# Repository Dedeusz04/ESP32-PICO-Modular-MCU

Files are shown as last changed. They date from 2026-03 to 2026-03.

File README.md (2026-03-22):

# ESP32-PICO Modular MCU

A modular hardware design based on the ESP32-PICO microcontroller, split into separate, specialized boards for the processor, power supply, and clock management to ensure high flexibility and easier troubleshooting in embedded development.

## Key Features
- **Modular Architecture**: Core system functionality is divided into distinct, easily interchangeable boards.
- **Processor Module** (`modul_procesora`): Houses the ESP32-PICO core, providing native Wi-Fi/Bluetooth capabilities and GPIO breakouts.
- **Power Supply Module** (`modul_zasilania`): Dedicated hardware for voltage regulation and stable power distribution to all components.
- **Clock Module** (`modul_zegara`): Handles precise clock generation and timing logic.
- **Custom Component Library**: Includes a comprehensive custom Autodesk EAGLE library (`proj_biblioteka.lbr`) with all necessary footprints and symbols used.

For a detailed description of the design, schematic choices, and PCB layouts, refer to the final project report included in this repository: [raport_koncowy_tem1 2 (1).pdf](raport_koncowy_tem1%202%20%281%29.pdf).

## Modules Overview
| Module | Schematic File | Board File | Description |
|---|---|---|---|
| **Processor Module** | `modul_procesora.sch` | `modul_procesora.brd` | Core ESP32-PICO system |
| **Power Supply** | `modul_zasilania.sch` | `modul_zasilania.brd` | Voltage regulation and power management |
| **Clock Module** | `modul_zegara.sch` | `modul_zegara.brd` | Precise timers and RTC |

## Usage
The hardware designs are provided as Autodesk EAGLE files.
1. Clone or download this repository.
2. Open Autodesk EAGLE and ensure `proj_biblioteka.lbr` is added to your active libraries.
3. Open the `.sch` and `.brd` files to view, modify, or manufacture the schematics and PCB designs.

## Contributors
- **Bartosz Kępa**
- **Jan Jamro**
- **Aleksandra Kuś**

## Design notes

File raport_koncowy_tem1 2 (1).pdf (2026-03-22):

| Silesian University of Technology Faculty of Automatic Control, Electronics and Computer Science Department of Graphics, Computer Vision and Digital Systems

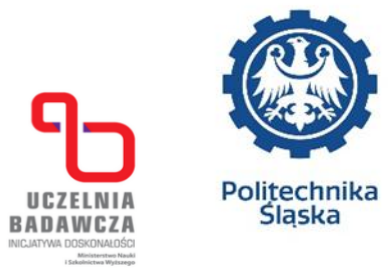
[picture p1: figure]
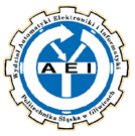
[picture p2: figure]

Rok akademicki | Rodzaj studiów*: | Przedmiot: | Grupa | Sekcja
2024/2025 | SSI | SMiW | 2 | 1
Termin oddania: | 02.07.2025 | Prowadzący: | Mgr inż. Jarosław Paduch
Imię i Nazwisko: Email kierownika: | Bartosz Kępa Jan Jamro Aleksandra Kuś Bk311386@student.polsl.pl

Karta projektu
Temat projektu:
1. Modułowa Jednostka centralna z procesorem ESP32-PICO-D4
- moduł zasilania wejście- 5v (USB) + podłączenie akumulatora z ładowarką
- moduł procesora z wejściami ISP i JTAG przyciski dwa (boot i reset)
- zegar RTC o dokładności około 2-5ppm
Opis projektu:

Projekt oparty jest na modułowej architekturze, co ułatwia rozbudowę i integrację. Jednostka centralna bazuje na ESP32-PICO-D4 z Wi-Fi, Bluetooth, interfejsami ISP i JTAG oraz przyciskami BOOT i RESET. Moduł zasilania wykorzystuje układ BQ24075 z funkcją PowerPath i przetwornicę TPS63020, zapewniając stabilne 3.3V z USB-C lub akumulatora Li-Ion 18650. Zegar RTC DS3231 zapewnia wysoką dokładność (±2 ppm), kompensację temperaturową i zasilanie bateryjne (CR2032). Interfejs użytkownika stanowią mechaniczne przyciski Cherry MX Red. Całość zaprojektowana została z myślą o energooszczędności, kompaktowych wymiarach (płytki 5x6 cm) oraz niezawodności w pracy mobilnej i stacjonarnej.

### 1. Moduł zasilania wejście- 5v (USB) + podłączenie akumulatora z ładowarką

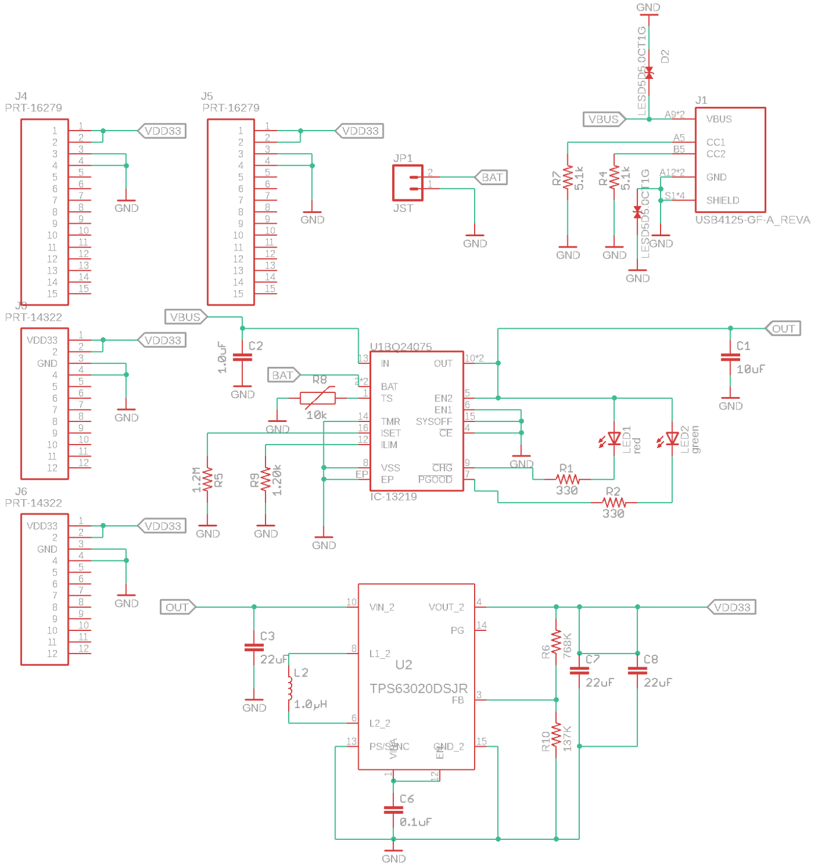
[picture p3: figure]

Rys. 1. Schemat modułu zasilania

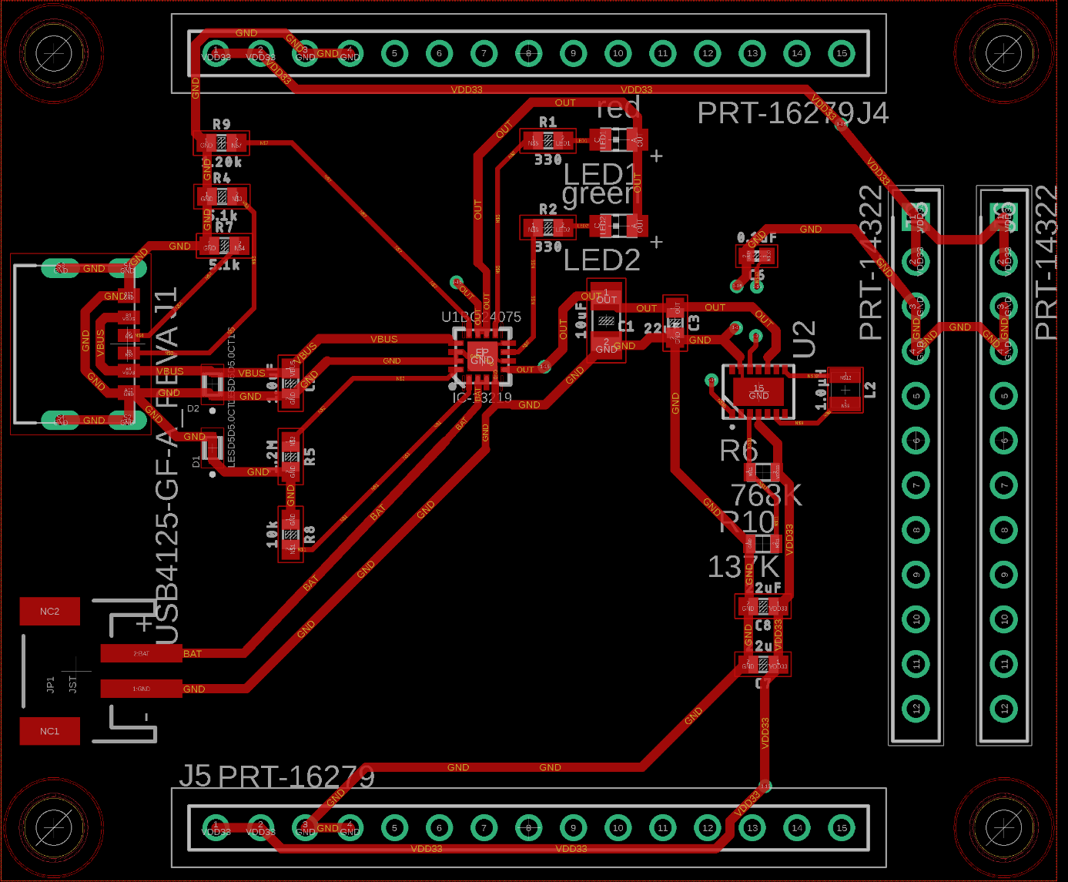
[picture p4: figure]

Rys. 2. Projekt płytki - bez wylanej masy, top warstwa

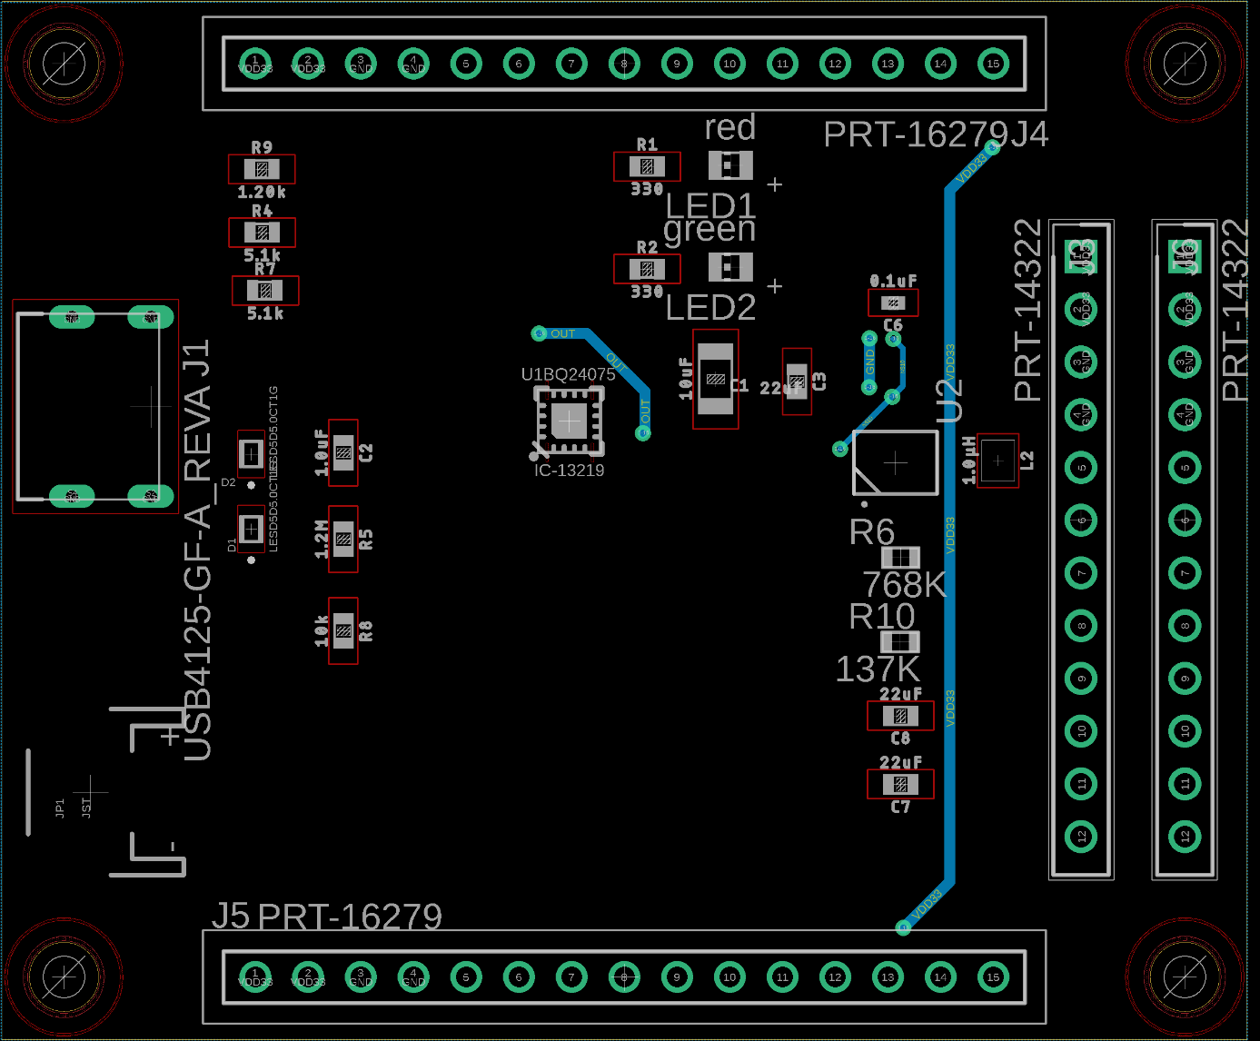
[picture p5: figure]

Rys. 3. Projekt płytki - bez wylanej masy, bottom warstwa

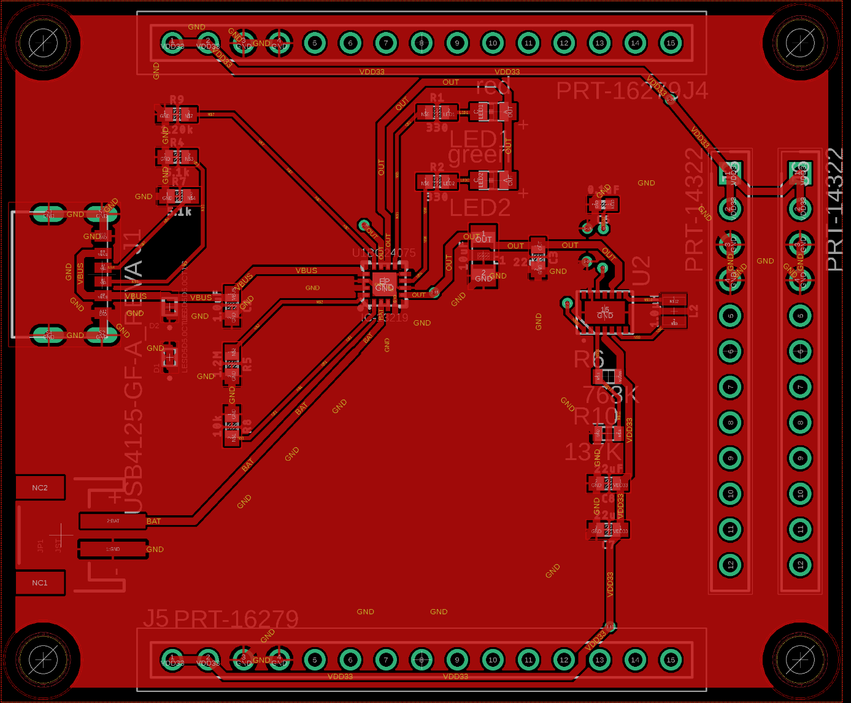
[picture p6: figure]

Rys. 4. Projekt płytki - z wylaną masy, top warstwa

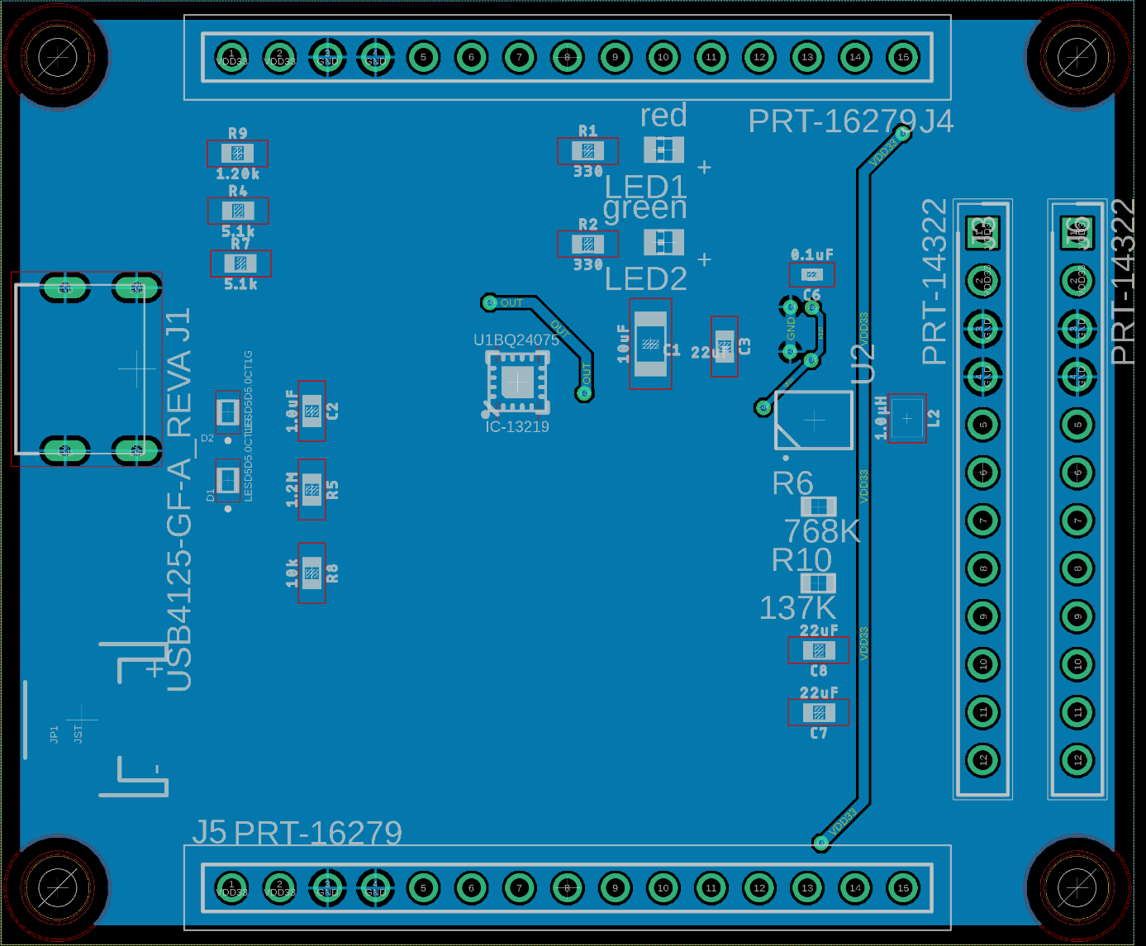
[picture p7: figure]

Rys. 5. Projekt płytki - z wylaną masą, bottom warstwa

Opis schematu modułu zasilania projektu:

Moduł zasilania opiera się na złączu USB-C (USB4125-GF-A) i układzie BQ24075, realizującym inteligentne przełączanie źródła zasilania. Przy podłączonym USB układ zasila system i ładuje akumulator Li-Ion 18650, a po odłączeniu automatycznie przechodzi na zasilanie bateryjne dzięki technologii PowerPath. Akumulator jest podłączony przez złącze JST PH 2.0mm, a termistor NTC (jeśli obecny) monitoruje temperaturę, blokując ładowanie przy zbyt wysokich wartościach. Dioda LED czerwona sygnalizuje ładowanie, a zielona wskazuje zasilanie z USB.

Napięcie z USB (5V) lub baterii (3.7V) jest stabilizowane przez przetwornicę buck-boost TPS63020DSJR, która dostarcza stałe 3.3V do ESP32-PICO-D4. Kondensatory (10µF, 22µF) zapewniają filtrowanie, a cewka (1.5µH) wspiera konwersję napięcia.

Dodatkowo port USB-C posiada Diody ESD-protection chroniące przed zbyt dużym napięciem. Całość masa jak i napięcie zasilania przekazywane są na złącza PRT-14322 oraz PRT-16279 służące do połączenia i zasilania pozostałych płytek.

Tab. 1. Tabela porównawcza przetwornic i stabilizatorów napięcia do 3,3V
Parametr | TPS63020DSJR | LTC3636 | MP2155 | AMS1117-3.3
Producent | Texas Instruments | Analog Devices | Monolithic Power Systems | Advanced Monolithic Systems
Typ | Buck-boost | Buck | Buck-Boost | Stabilizator liniowy
Zakres VIN | 1,8V - 5,5V | 3.1V - 20V | 2V – 5.5V | 4.75V - 15V (dla VOUT=3.3V)
Zakres VOUT | 1,2V - 5,5V | 0.6V - 5V | 1.5V - 5V | Stałe 3.3V
Maks. IOUT | 4A | 6A | 1A | 1A
Sprawność | Do 96% | Do 95% | Do 95% | (VOUT/VIN)*100%, np. 66% przy VIN=5V
Częstotliwość przełączania | 2.4MHz | 500kHz -4MHz | 1MHz | N/A
Cechy specjalne | Jednoindukcyjny, synchroniczna prostownia, tryb oszczędny | Wysoka efektywność, niski pobór prądu w trybie bez obciążenia | Niski prąd spoczynkowy, tryb oszczędny | Prosty, niskokosztowy, ale niska sprawność

Uzasadnienie wyboru TPS63020DSJR TI TPS63020 (https://www.ti.com/product/TPS63020)

- Wysoka sprawność (do 96%): Minimalizuje straty energii, szczególnie przy VIN > VOUT, w porównaniu do AMS1117, który traci energię jako ciepło (np. 0,34W przy VIN=5V, VOUT=3,3V, IOUT=200mA).

- Elastyczność napięcia: Działa zarówno przy VIN < VOUT (bateria <3,3V), jak i VIN > VOUT (USB 5V), w przeciwieństwie do AMS1117, który wymaga VIN > VOUT.
- Duży prąd wyjściowy (4A): Zapewnia zapas dla przyszłych rozszerzeń projektu.
- Zgodność z TI: Ułatwia integrację z innymi komponentami od Texas Instruments.

Dlaczego nie np, stabilizator liniowy (AMS1117)?

Stabilizatory liniowe, takie jak AMS1117, są mniej efektywne, ponieważ nadmiar energii jest rozpraszany jako ciepło. Przy VIN=5V i VOUT=3,3V sprawność wynosi tylko ~66%, co wymaga radiatora. Ponadto, gdy napięcie baterii spadnie poniżej 4,3V, AMS1117 nie może utrzymać 3,3V, co czyni go nieodpowiednim dla aplikacji z baterią.

Tab. 2. Tabela porównawcza modułów podtrzymania akumulatorowego

Parametr | BQ24075 | TP4056 | TP4057 | LTC4054
Producent | Texas Instruments | NanJing Top Power | NanJing Top Power | Analog Devices
Prąd ładowania | Do 1,5A | Do 500mA | Do 500mA | Do 1A
Napięcie wejściowe | 4.35V – 6.4V | 4.0V – 8.0V | 4.0V – 6.5V | 4.25V - 6V
Napięcie baterii | 2.8V – 4.2V | 3.7V - 4,2V | 3,7V - 4,2V | 2.5V – 4.2V
Zarządzanie ścieżką zasilania | Tak | Nie | Nie | Tak
Dodatkowe cechy | Programowalny prąd, limit prądu wejściowego | Ochrona przed przeładowaniem, zwarcia | Podobne do TP4056 | Automatyczne ponowne ładowanie, wykrywanie niskiego napięcia

Uzasadnienie wyboru BQ24075 TI BQ24075 (https://www.ti.com/product/BQ24075)

- Zarządzanie ścieżką zasilania: Umożliwia jednoczesne ładowanie baterii i zasilanie układu, eliminując potrzebę dodatkowych diod lub przełączników, w przeciwieństwie do TP4056/TP4057.
- Wyższy prąd ładowania (1,5A): Umożliwia szybsze ładowanie lub obsługę większych baterii w porównaniu do 1A w TP4056/TP4057.
- Zaawansowane funkcje: Programowalny prąd ładowania i limit prądu wejściowego zwiększają elastyczność.
- Zgodność z TI: Ułatwia integrację z innymi komponentami.

Dlaczego nie np, TP4056/TP4057?

- Brak zarządzania ścieżką zasilania: Wymaga dodatkowych komponentów do przełączania między USB a baterią.
- Niższy prąd ładowania (500A): Mniejsza elastyczność w porównaniu do BQ24075.
- Mniejsza liczba funkcji: Brak zaawansowanych opcji, takich jak programowalny prąd czy limit wejściowy.

Spis elementów układu:

Symbol | Nazwa / Model | Funkcja i opis
J1 | USB4125-GF-A | Złącze USB-C do zasilania i ładowania systemu
JP1 | JST PH 2.0mm | Złącze do podłączenia akumulatora Li-Ion
J3,J6 | PRT-14322 | Złącze 12 pin o standardowym rastrze 2,54 mm do przekazania masy i Vcc pozostałym płytkom
J4,J5 | PRT-16279 | Złącze 15 pin o standardowym rastrze 2,54 mm do przekazania masy i Vcc pozostałym płytkom
U1 | BQ24075 | Układ ładowania Li-Ion z funkcją Power Path
U2 | TPS63020DSJR | Przetwornica buck-boost do stabilizacji 3.3V
C1 | 10µF | Kondensator filtrujący wejście BQ24075
C2 | 10µF | Kondensator filtrujący wyjście BQ24075
C3 | 22µF | Kondensator filtrujący wejście TPS63020DSJR
C7,C8 | 22µF | Kondensator filtrujący wyjście TPS63020DSJR
C6 | 0.1µF | Filtrowanie TPS63020DSJR
L1 | 1.5µH | Cewka dla TPS63020DSJR
R1,R2 | 330Ω | Rezystor ograniczający prąd diody LED
R9 | 1.2kΩ | Programowanie prądu ładowania (ILIM)
R5 | 1.2MΩ | Programowanie prądu ładowania (ISET)
R7,R4 | 5.1kΩ | Rezystory podciągające CC1/CC2 w złączu USB-C
R10,R6 | 137kΩ,768kΩ | Dzielnik napięcia dla FB TPS61022 - do ustawienia wyjścia na 5 V
LED1 | Diode LED Red | Dioda LED czerwona sygnalizacja ładowania
LED2 | Diode LED Green | Dioda LED zielona sygnalizacja zasilania z USB
D2,D1 | ESD5D5.0CT1G | Dioda ESD protection
BAT | Do podłączenia Li-Ion 18650 | Akumulator 3.7V 1000-3000mAh

Wnioski

Moduł zasilania dla ESP32-PICO-D4 został zaprojektowany z myślą o pracy z zasilaniem USB i akumulatorowym. Kluczowym elementem jest BQ24075, zapewniający zarządzanie ścieżką zasilania i bezpieczne ładowanie. Przetwornica TPS63020DSJR gwarantuje stabilne 3.3V z efektywnością (do 96%), a złącze USB4125-GF-A redukuje koszty posiadając jedynie niezbędne piny do bezpiecznego zasilania/ładowania.

### 2. Moduł procesora z wejściami ISP i JTAG przyciski dwa (boot i reset)

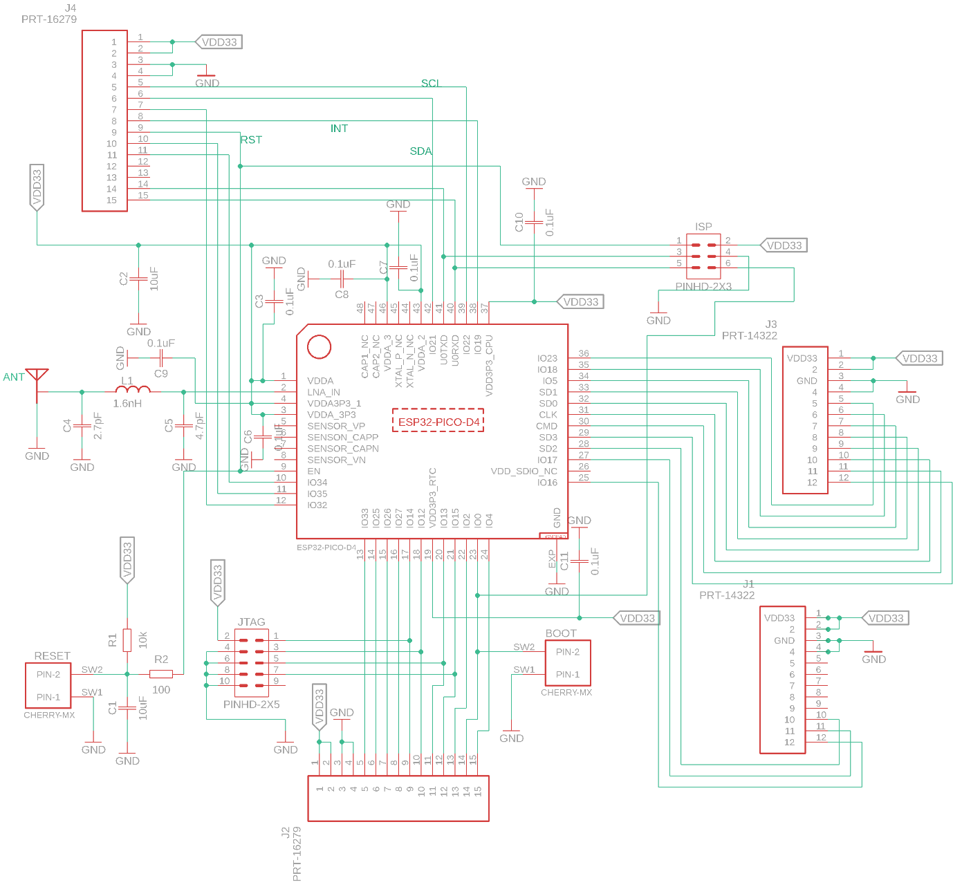
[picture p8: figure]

Rys. 6. Schematu modułu procesora

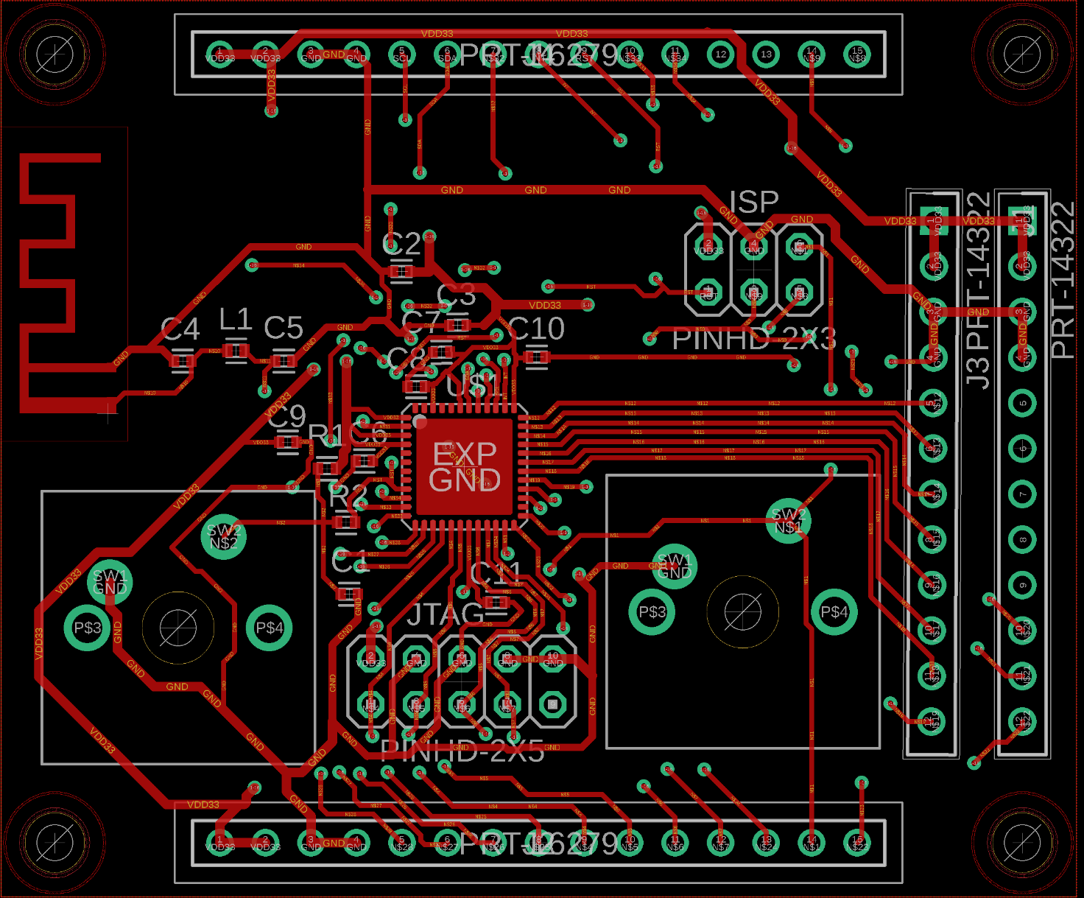
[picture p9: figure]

Rys. 7. Projekt płytki modułu procesora – warstwa TOP bez masy

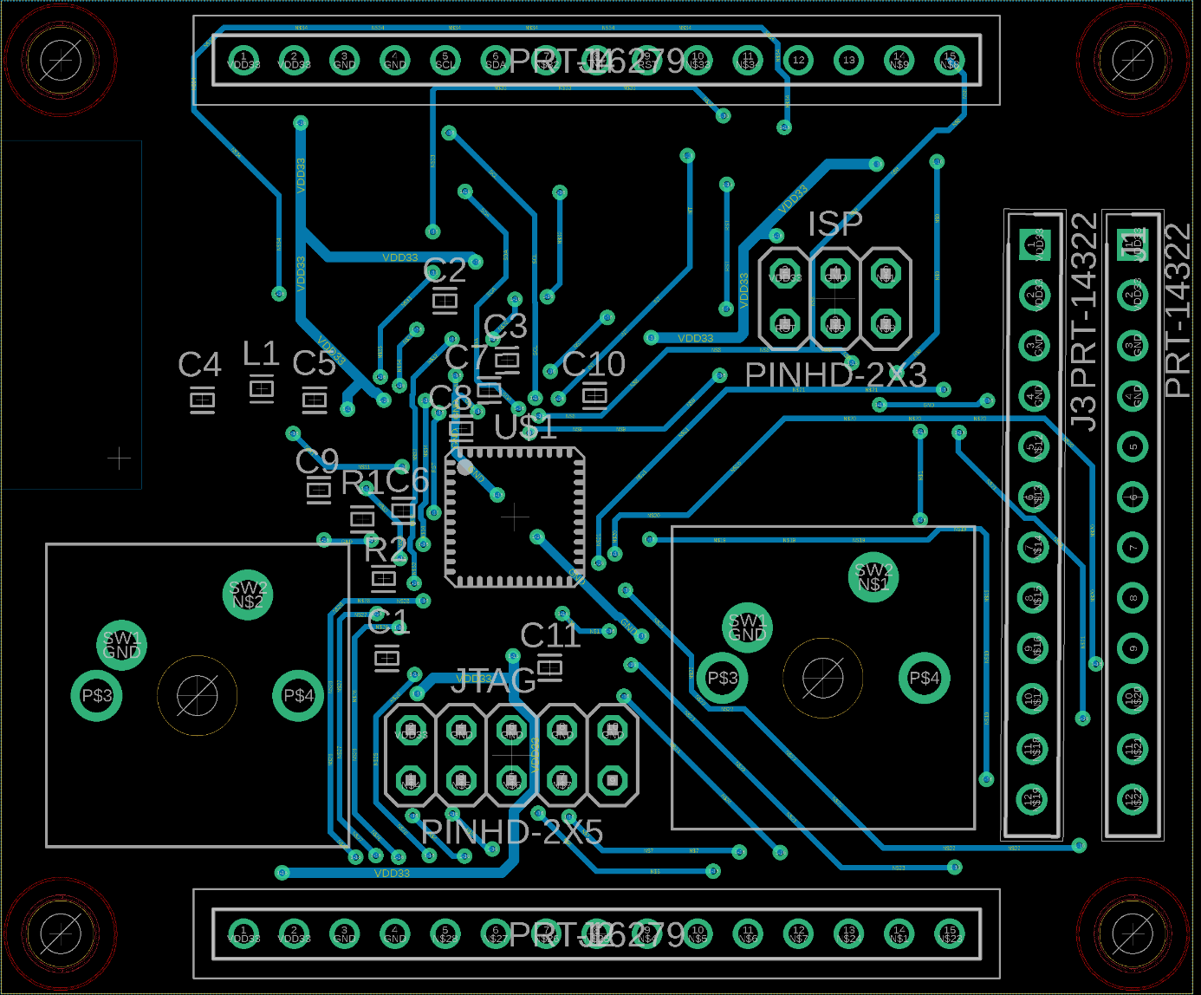
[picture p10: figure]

Rys. 8. Projekt płytki modułu procesora – warstwa BOTTOM bez masy

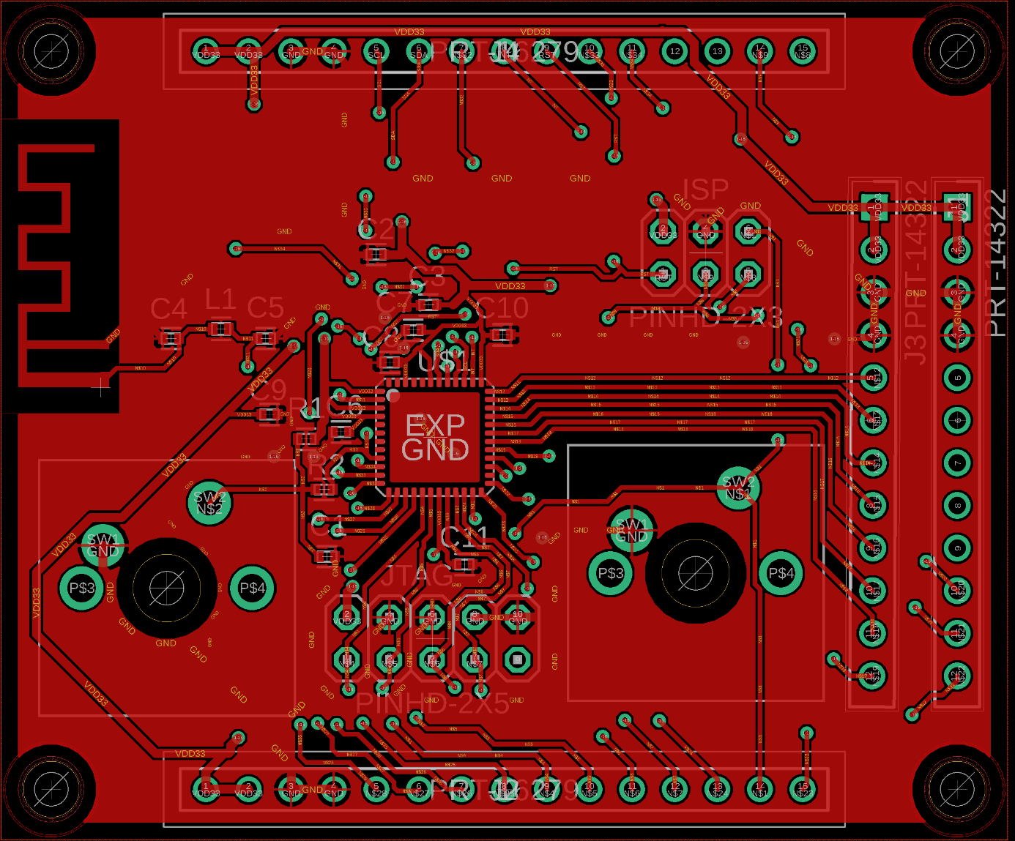
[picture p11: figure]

Rys. 9. Projekt płytki modułu procesora – warstwa TOP z wylaną masą

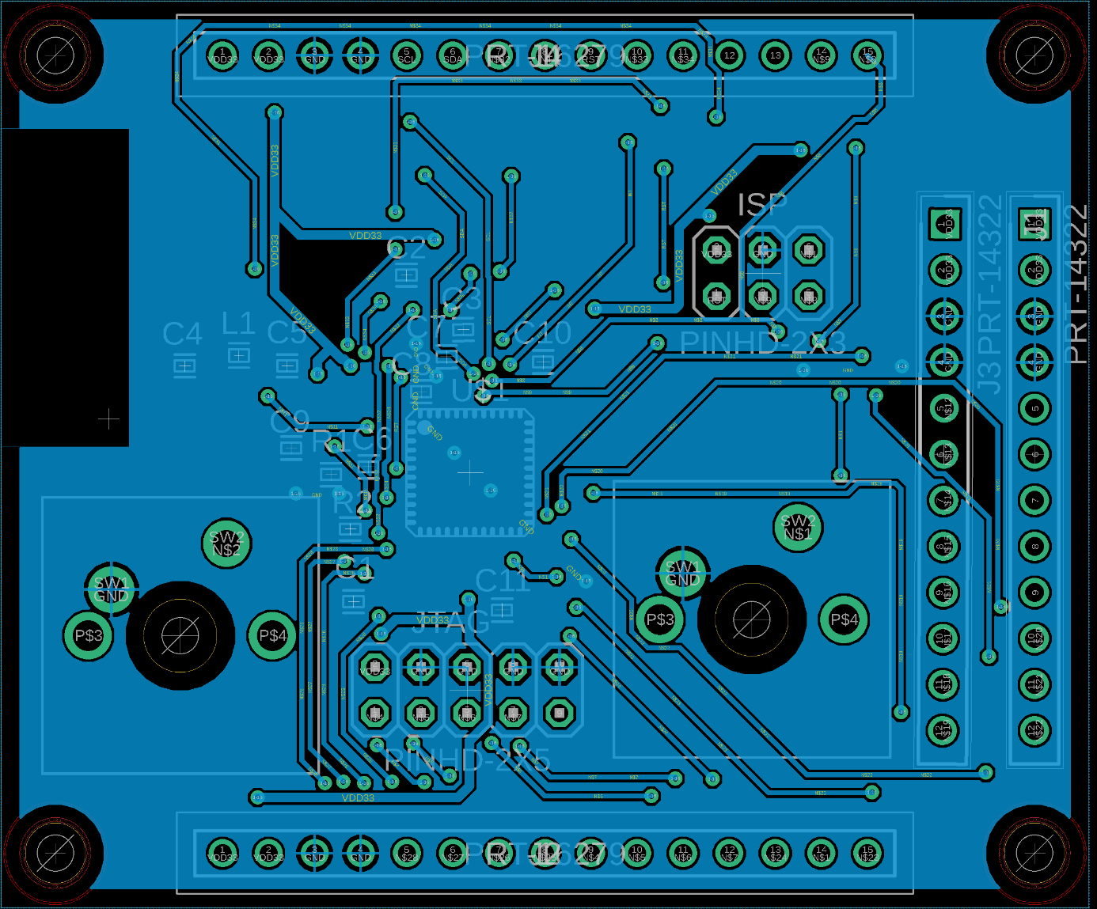
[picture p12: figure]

Rys. 10. Projekt płytki modułu procesora – warstwa BOTTOM z wylaną masą

Opis schematu modułu procesora:
Moduł zrealizowany na procesorze ESP32-PICO-D4. Zawiera złącza do programowania i debugowania: ISP oraz JTAG, do czego należy wykorzystać programator ESP-Prog. Do ISP wykorzystano piny U0RXD oraz U0TXD natomiast dla JTAG piny IO12, IO13, IO14, IO15. Dodatkowo do procesora podłączono dwa przyciski Cherry MX Red– BOOT do przejścia w tryb programowania oraz RESET do restartu procesora, a także antenę WiFi/Bluetooth. Wykorzystano również rezystory, kondensatory oraz cewkę.
Cały moduł zasilany jest oddzielnym modułem zasilania, opisanym w poprzedniej części.
Dodatkowo z procesora na złącza wyprowadzane są sygnały SDA, SCL, INT i RST niezbędne do właściwego działania zegara, opisanego w kolejnej części. Także zostały wyprowadzone na złącza rozszerzeń pozostałe sygnały procesora czyniąc ją w pełni modułową jednostką centralną.
Sam procesor posiada 4 MB pamięci Flash, Wi-Fi 802.11 b/g/n i Bluetooth 4.2 BR/EDR, wewnętrzny oscylator, filtry, i zarządzanie energią. Wymiary 7mm x 7mm, w uśpieniu pobiera bardzo niewielki prąd mnieszy niż 10 uA.

Tab. 3. Porównanie przycisków
Cecha | Cherry MX Red | Gateron Red | Razer Green
Typ | Liniowy | Liniowy | Klikany
Siła nacisku | 45cN | 45cN | 55cN
Długość | 4mm | 4mm | 4mm
Temperatura pracy | Od –40°C do 85°C | Od –40°C do 85°C | Od –40°C do 80°C
Żywotność mechanicza | 50 milionów kliknięć | 60 milionów kliknięć | 80 milionów kliknięć
Rezystancja styku | < 200mΩ | < 200mΩ | < 200mΩ
Dźwięk | Cichy | Cichy | Głośny klik
Cena za sztukę | < 1zł | 1-2 zł | 130 zł

Przyciski Cherry MX Red charakteryzują się płynnością nacisku oraz cichym dzwiękiem, a także estetycznym wyglądem. Ich parametry są bardzo dobre, a dodatkowo cena niewysoka, dlatego są dobrym wyborem do projektu.

Tab.4. Porównanie ESP32-PICO-D4 z ESP8266
Cecha | ESP32-PICO-D4 | ESP8266
Pamięć Flash | 4MB wbudowane | 4MB zewnętrzne
Pamięć RAM | 520 KB SRAM | Około 160KB RAM
WiFi | 802.11 b/g/n | 802.11 b/g/n
Bluetooth | BT 4.2 + BLE | Brak
GPIO | Około 20 (zależnie od konfiguracji) | 11-17 (zależnie od wersji)
JTAG debug | Tak | Nie
Rozmiar | 7mm x 7mm | Około 16mm x 24mm
Pobór w uśpieniu | < 10 mA | Około 20uA
Cena | 10 – 15 zł | 7 – 12 zł

ESP32-PICO-D4 jest nowocześniejszy, szybszy i bardziej funkcjonalny przy niewiele wyższej cenie.
Wnioski

Zaprojektowany moduł umożliwia zarówno programowanie (przez ISP), jak i debugowanie (przez JTAG) mikrokontrolera ESP32-PICO-D4. Zastosowanie przycisków BOOT i RESET pozwala na ręczne wprowadzanie układu w tryb programowania oraz na szybki restart systemu bez konieczności odłączania zasilania. Cały moduł jest niewielki, mieszcząc się na płytce 5cm x 5cm.
Umożliwia on rozbudowanie całego projektu o kolejne moduły, które będą przez niego obsługiwane.

### 3. Zegar RTC o dokładności około 2-5ppm:

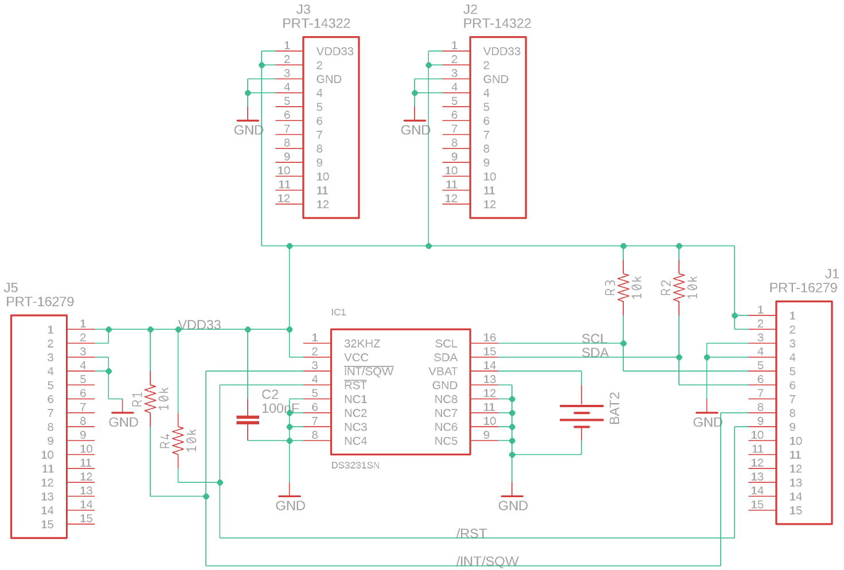
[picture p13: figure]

Rys. 11. Schematu modułu zegara RTC

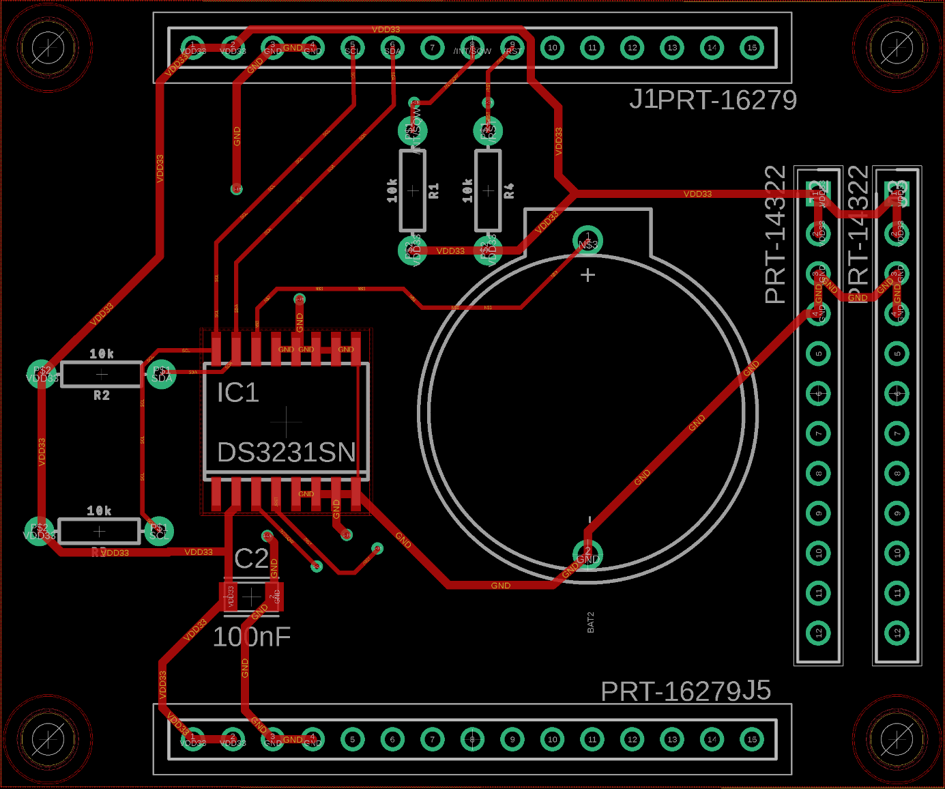
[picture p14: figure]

Rys. 12. Projekt płytki - bez wylanej masy, top warstwa

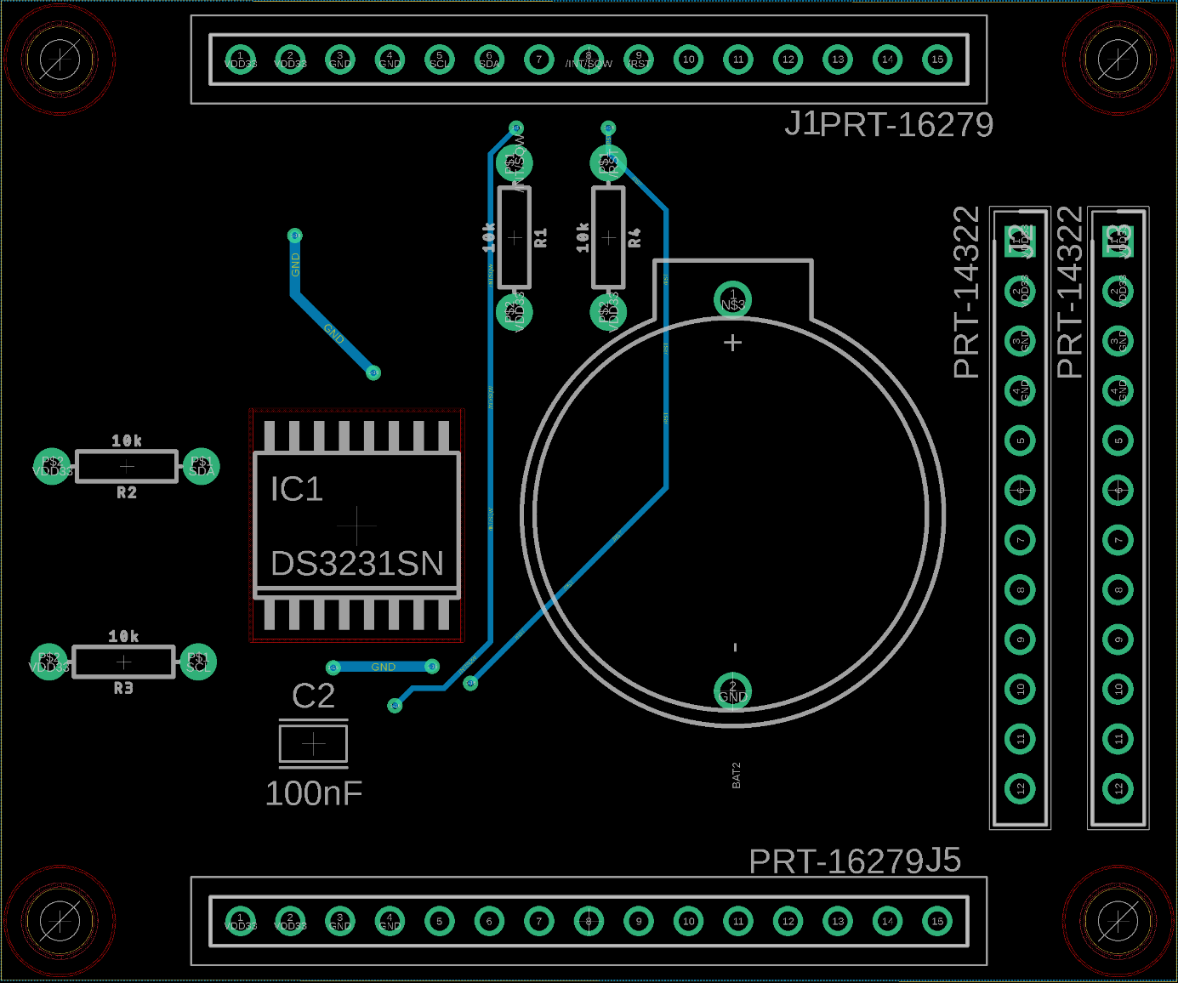
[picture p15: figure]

Rys. 13. Projekt płytki - bez wylanej masy, bottom warstwa

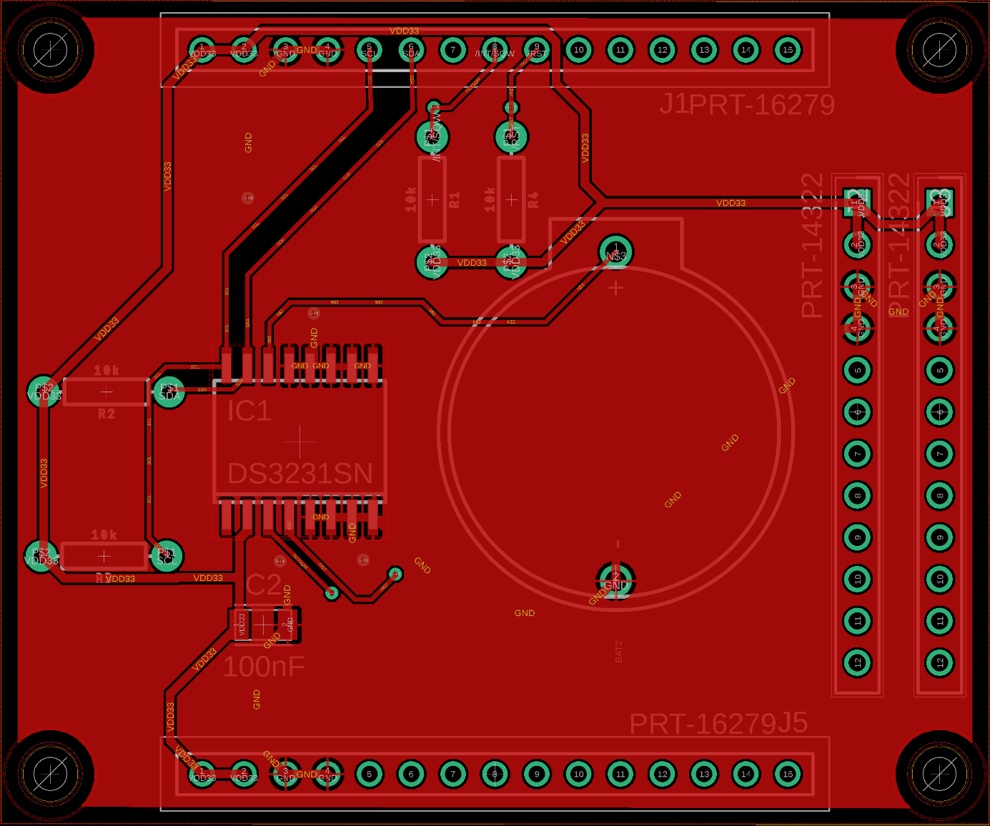
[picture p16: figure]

Rys. 14. Projekt płytki – z wylaną masą, top warstwa

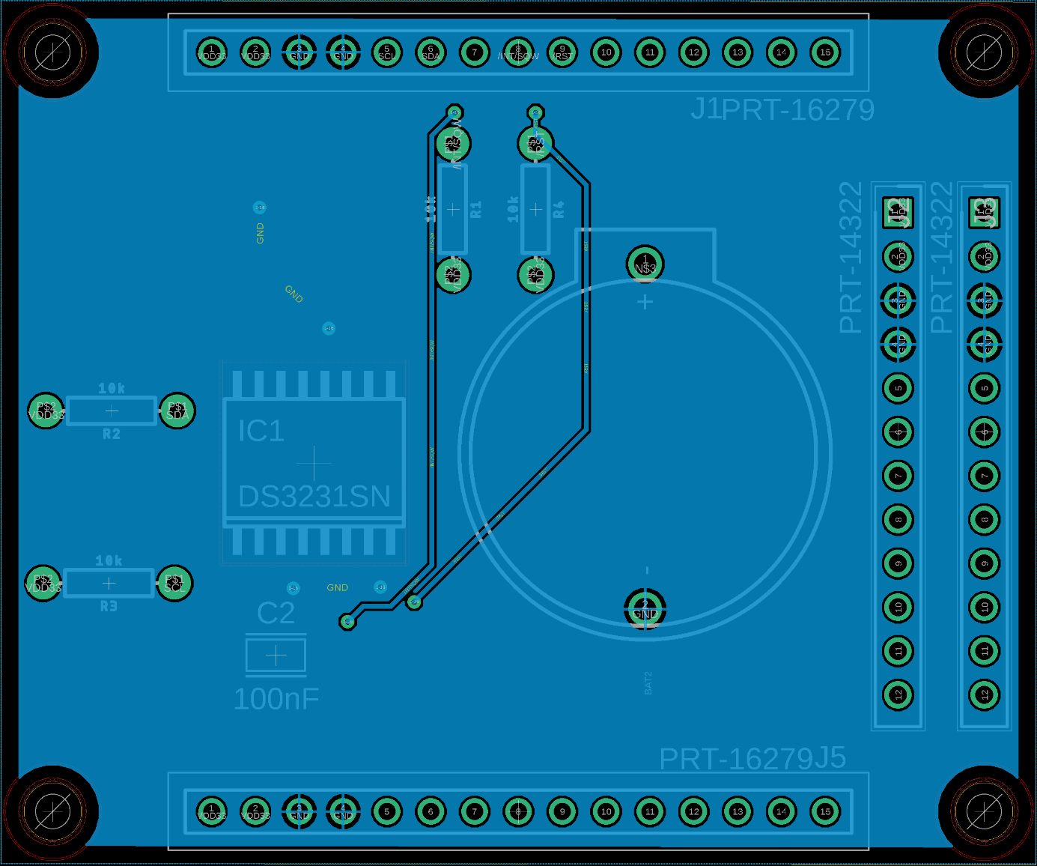
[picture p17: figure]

Rys. 15. Projekt płytki – z wylaną masą, bottom warstwa

Opis schematu modułu zegara RTC:
Na płytce zegara DS3231 zastosowano dwa rezystory podciągające o wartości 10 kΩ w obudowie SMD 0805, które łączą linie SDA i SCL z napięciem 3,3 V. Rezystory te gwarantują, że magistrala I²C zawsze wraca do stanu wysokiego, nawet gdy żaden układ nie przeciąga jej w dół, co zapobiega szumom i nieprawidłowym odczytom. Bezpośrednio przy pinie VCC DS3231 znajduje się ceramiczny kondensator 100 nF (X7R, 0805), którego niska wartość ESR i dobra stabilność temperaturowa umożliwia:
- tłumienie wysokoczęstotliwościowych zakłóceń na linii zasilania,
- szybkie dostarczanie prądu przy nagłych pikach poboru (np. podczas odbierania lub nadawania danych).
Aby zachować ciągłość pomiaru czasu przy zaniku głównego zasilania, moduł wyposażono w gniazdo na baterię typu CR2032, montowane powierzchniowo. Dodatni biegun ogniwa podłączono do pinu VBAT, a ujemny do masy. W praktyce oznacza to, że:
- gdy VDD33 spadnie poniżej progu, DS3231 automatycznie przełącza się na zasilanie bateryjne,
- wskazania zegara pozostają poprawne przez wiele lat – nawet w przypadku długotrwałego braku zasilania.
Na płytce zastosowano dwa złącza PRT-14322 oraz dwa złącza PRT-16279 o standardowym rastrze 2,54 mm. Złącze J5,J3,J2, służące wyłącznie do dostarczania zasilania, ma tylko dwa aktywne piny:
- pin 1,2 to VDD33,
- pin 3,4 — GND.
Natomiast złącze J1 wyprowadza wszystkie sygnały niezbędne do współpracy DS3231 z zewnętrznym układem: dostępne są tu piny VDD33, GND, linie SCL i SDA magistrali I²C, wyjście przerwania lub sygnału kwadratowego INT/SQW oraz opcjonalny pin RESET. Rozmieszczenie pinów w dwóch rzędach ułatwia prowadzenie ścieżek i montaż przewodów w zestawach prototypowych czy obudowach modułowych. Dzięki temu zestawowi złączy moduł jest wszechstronnie gotowy do integracji z różnymi mikrokontrolerami lub systemami pomiarowymi.

Tab. 5. Tabela porównawcza zegarów RTC
Model | DS3231 | DS1307 | PCF85263A | MCP79410
Dokładność | ±2 ppm | ~ 20–50 ppm | ~10-50 ppm | ±5 ppm
Interfejs | I²C do 400 kHz | I²C do 100 kHz | I²C do 400 kHz | I²C do 400 kHz
Komunikacja | I²C | I²C | I²C/SPI | I²C
Wbudowany oscylator | Tak | Nie | Tak | Nie
Kompensacja temperatury | Tak | Nie | Częściowa | Nie
Napięcie wejściowe | 2,3–5,5V | 5V (moduł), 2,0– 3,5V | 1,8–3,6V | 1,8 – 5,5 V
Napięcie wyjściowe | – | – | – | –
Maksymalny prąd | ~200 µA | 800 nA | ~200 nA | ~230 µA
Bateria | Brak (CR2032) | Brak (CR2032) | Brak (CR1220) | Brak (CR2032)
Napięcie baterii VBAT | 2,3 V…5,5 V | 2,0 V…3,5 V | — (pomija VBAT; bat. w zewn. układzie) | 1,8 – 5,5 V
Backup bateryjny | Ręczne przełączanie, UL-recognized | Automatyczne przełączenie przy VCC<VTP | Detekcja niskiego VDD, alarm VL | Automatyczne przełączanie
Zakres temp. pracy | 0 °C…+70 °C (S) –40 °C…+85 °C (SN) | 0 °C…+70 °C (Z) –40 °C…+85 °C (ZN) | –40 °C…+85 °C | –40 … +85 °C
Pinout | 16-pin SOIC (300 mil) | 8-pin DIP-8 / SO-8 | 8-pin SO-8 / TSSOP-8 | 8-pin SO-8 / MSOP-8
Funkcje dodatkowe | TCXO, czujnik temp., kalibracja starzenia | 56 B SRAM, wyjście SQW/OUT | alarmy, timer, CLKOUT z 4 trybami | kalendarz, 1 kB EEPROM, 2 alarmy, PWM, cyfrowy trim
Obudowa | SO-16 | DIP-8 / SO-8 | SO-8 / TSSOP-8 | SO-8 / MSOP-8
Koszt | ~30 zł | ~23 zł | ~30 zł | ~10 zł
Wymaga kwarcu zewn.? | Nie | Tak (32.768 kHz) | Nie | Tak (32,768 kHz)
Uwagi | Bardzo dokładny | Tani, popularny, | Nowoczesny, trudniej dostępny | Dodatkowa pamięć, brak kompensacji

W projekcie zdecydowano się na zastosowanie układu RTC DS3231. Wybór ten został podjęty na podstawie analizy parametrów kilku popularnych układów czasu rzeczywistego. Celem było znalezienie rozwiązania, które zapewni wysoką dokładność oraz łatwość integracji z mikrokontrolerem ESP32-PICO-D4.
- Zapewnia wysoką dokładność rzędu ±2 ppm, co spełnia wymagania projektowe dotyczące precyzji odmierzania czasu.
- Posiada wbudowany oscylator kwarcowy oraz kompensację temperaturową, co gwarantuje stabilne działanie niezależnie od warunków otoczenia.
- Nie wymaga zewnętrznego rezonatora, dzięki czemu upraszcza projektowanie układu PCB i redukuje liczbę komponentów.
- Umożliwia zasilanie bateryjne (np. CR2032), co pozwala na podtrzymanie czasu w przypadku przerwy w zasilaniu głównym.
- Komunikuje się przez magistralę I²C, co ułatwia integrację z mikrokontrolerem ESP32-PICO-D4 i zmniejsza zapotrzebowanie na linie sygnałowe.
Ze względu na powyższe cechy, DS3231 został uznany za najbardziej odpowiedni układ RTC do realizacji założeń projektu.

Wnioski:
Wykorzystanie układu DS3231 z wbudowanym rezonatorem TCXO i kompensacją temperaturową zapewnia wyjątkową dokładność pomiaru czasu (rzędu ±2 ppm) w szerokim zakresie temperatur, a dzięki automatycznemu przełączaniu na zasilanie bateryjne (ogniwo CR2032) moduł zachowuje ciągłość wskazań nawet przy zaniku głównego VDD. Krótkie ścieżki do rezystorów podciągających 10 kΩ na liniach SDA ,SCL, /RST, /INT/SQW oraz kondensator 100 nF przy pinie VCC tłumią zakłócenia i stabilizują napięcie, co przekłada się na bezbłędną komunikację I²C. Złącza PRT-14322 (J5 i J1) oraz PRT-16279 (J2 i J3) o wyraźnym pinoucie i zwartej, kątowej formie znacznie ułatwiają montaż i integrację z mikrokontrolerami czy obudowami modułowymi. Ponadto pozostawione pola lutownicze na dodatkowe filtry czy diody ochronne pozwalają w prosty sposób dostosować projekt do specyficznych wymagań środowiskowych lub norm EMC.

Oceny wystawione przez kierownika projektu:

Praca nad projektem przebiegała bardzo dobrze, z pełnym zaangażowaniem i przestrzeganiem terminów. Członkowie zespołu wykazali się inicjatywą i wsparciem dla siebie nawzajem, co przełożyło się na efektywną pracę. Przy ocenie brano pod uwagę zarówno wartość merytoryczną wkładu, jak i zaangażowanie w pracę zespołową.
Jan Jamro: 5
Aleksandra Kuś: 5

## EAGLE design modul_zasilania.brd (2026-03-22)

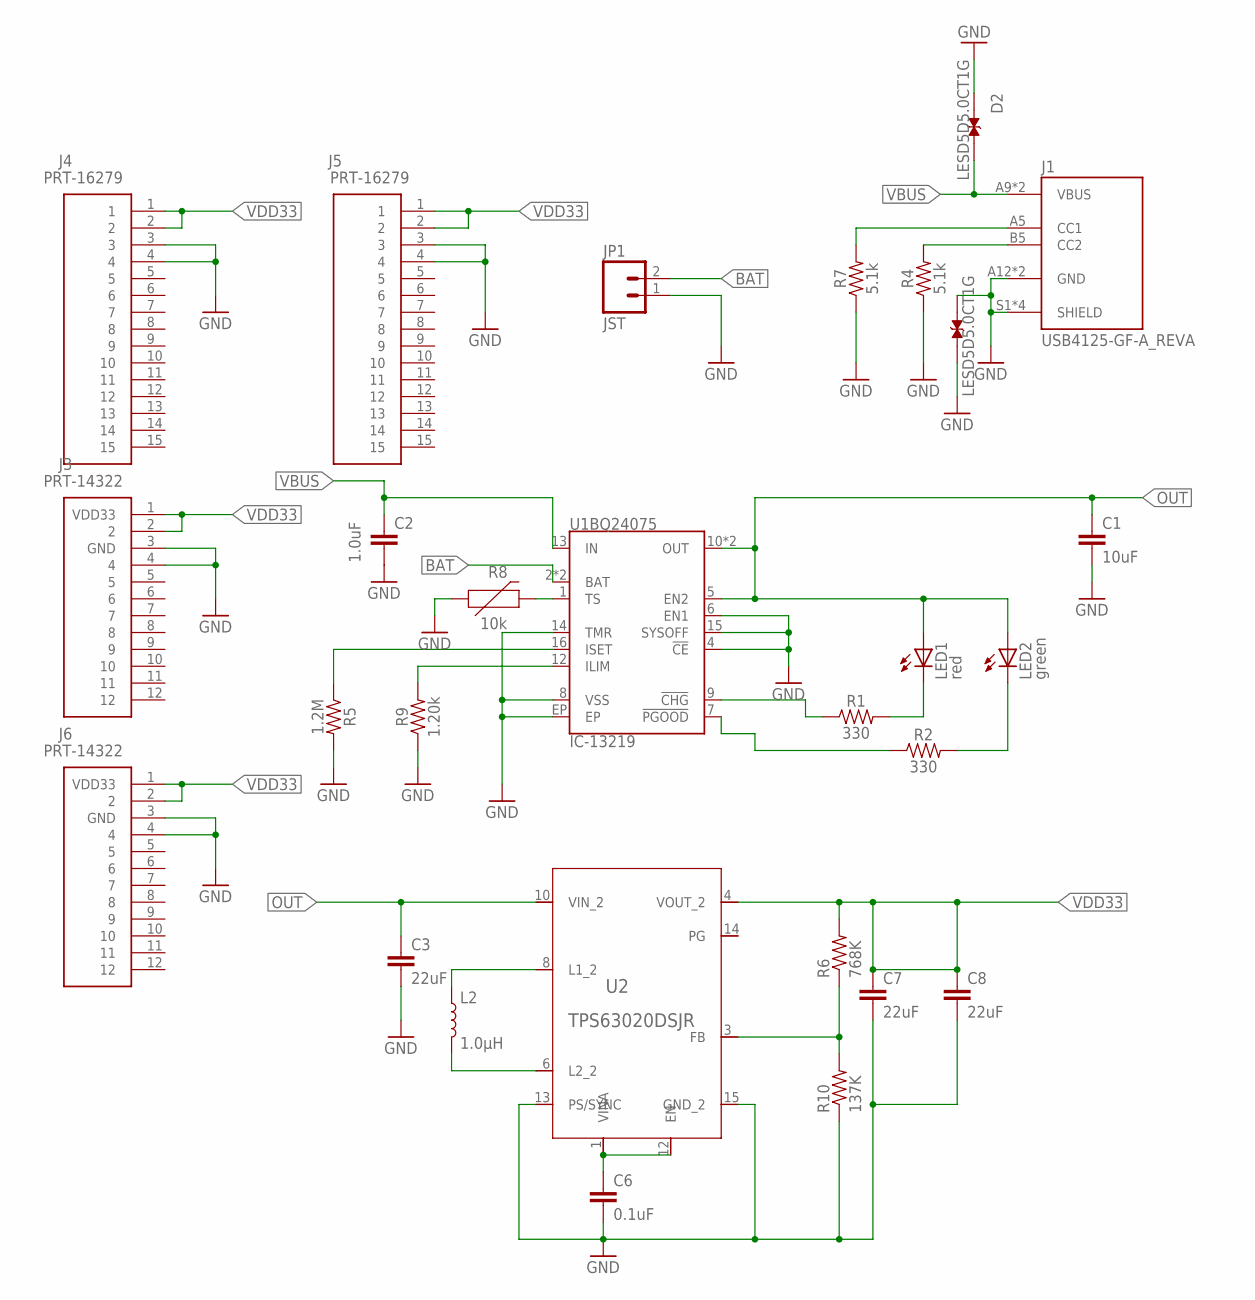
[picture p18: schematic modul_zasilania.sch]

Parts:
C1: 10uF; 1206
C2: 1.0uF; 0603
C3, C7, C8: 22uF; 0603
C6: 0.1uF; 0402
D1, D2: LESD5D5.0CT1G; TVS_LESD5D5.0CT1G
J1: USB4125-GF-A_REVA; GCT_USB4125-GF-A_REVA
J3, J6: PRT-14322; RHDR12W87P0X254_1X12_3103X250X
J4, J5: PRT-16279; PRT16279
JP1: JST; JST-2-SMD
L2: 1.0μH; 0805-WIDE
LED1: red; CHIP-LED0805
LED2: green; CHIP-LED0805
R1, R2: 330; 0603
R4, R7: 5.1k; 0603
R5: 1.2M; 0603
R6: 768K; 0603
R8: 10k; 0603@1
R9: 1.20k; 0603
R10: 137K; 0603
U1BQ24075: IC-13219; PVQFN-N16
U2: TPS63020DSJR; R-PVSON-N14

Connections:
BAT: JP1.2, U1BQ24075.2 (BAT), U1BQ24075.3 (BAT)
GND: C1.2, C2.2, C3.2, C6.2, C7.2, C8.2, D1.1, D1.2, D2.1, J1.A12 (GND), J1.B12 (GND), J1.S1 (SHIELD), J1.S2 (SHIELD), J1.S3 (SHIELD), J1.S4 (SHIELD), J3.3 (GND), J3.4, J4.3, J4.4, J5.3, J5.4, J6.3 (GND), J6.4, JP1.1, R4.1, R5.2, R7.1, R8.1, R9.1, R10.1, U1BQ24075.4 (!CE!), U1BQ24075.6 (EN1), U1BQ24075.8 (VSS), U1BQ24075.14 (TMR), U1BQ24075.15 (SYSOFF), U1BQ24075.EP, U2.13 (PS/SYNC), U2.15 (GND_2)
LED1: LED1.C, R1.2
LED2: LED2.C, R2.2
unnamed: R8.2, U1BQ24075.1 (TS)
unnamed: R5.1, U1BQ24075.16 (ISET)
unnamed: J1.B5 (CC2), R4.2
unnamed: J1.A5 (CC1), R7.2
unnamed: R1.1, U1BQ24075.9 (!CHG!)
unnamed: R2.1, U1BQ24075.7 (!PGOOD!)
unnamed: R9.2, U1BQ24075.12 (ILIM)
unnamed: L2.2, U2.6 (L2_2)
unnamed: C6.1, U2.1 (VINA), U2.12 (EN)
unnamed: R6.1, R10.2, U2.3 (FB)
unnamed: L2.1, U2.8 (L1_2)
OUT: C1.1, C3.1, LED1.A, LED2.A, U1BQ24075.5 (EN2), U1BQ24075.10 (OUT), U1BQ24075.11 (OUT), U2.10 (VIN_2)
VBUS: C2.1, D2.2, J1.A9 (VBUS), J1.B9 (VBUS), U1BQ24075.13 (IN)
VDD33: C7.1, C8.1, J3.1 (VDD33), J3.2, J4.1, J4.2, J5.1, J5.2, J6.1 (VDD33), J6.2, R6.2, U2.4 (VOUT_2)

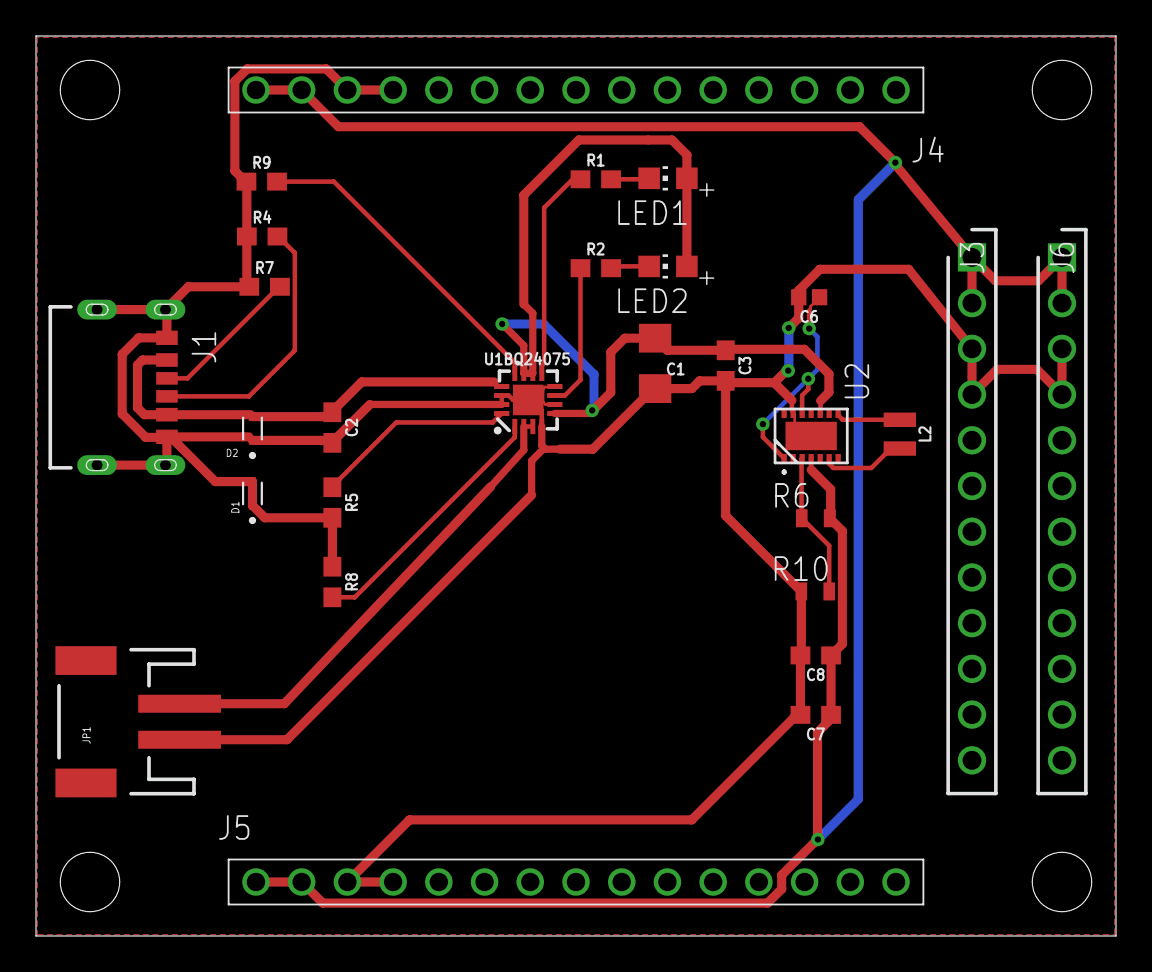
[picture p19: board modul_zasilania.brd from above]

Board: 2 copper layers, 60.0 x 50.0 mm, 32 parts (0 on the bottom side), 18 nets.

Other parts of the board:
STANDOFF1, STANDOFF2, STANDOFF3, STANDOFF4: STAND-OFF

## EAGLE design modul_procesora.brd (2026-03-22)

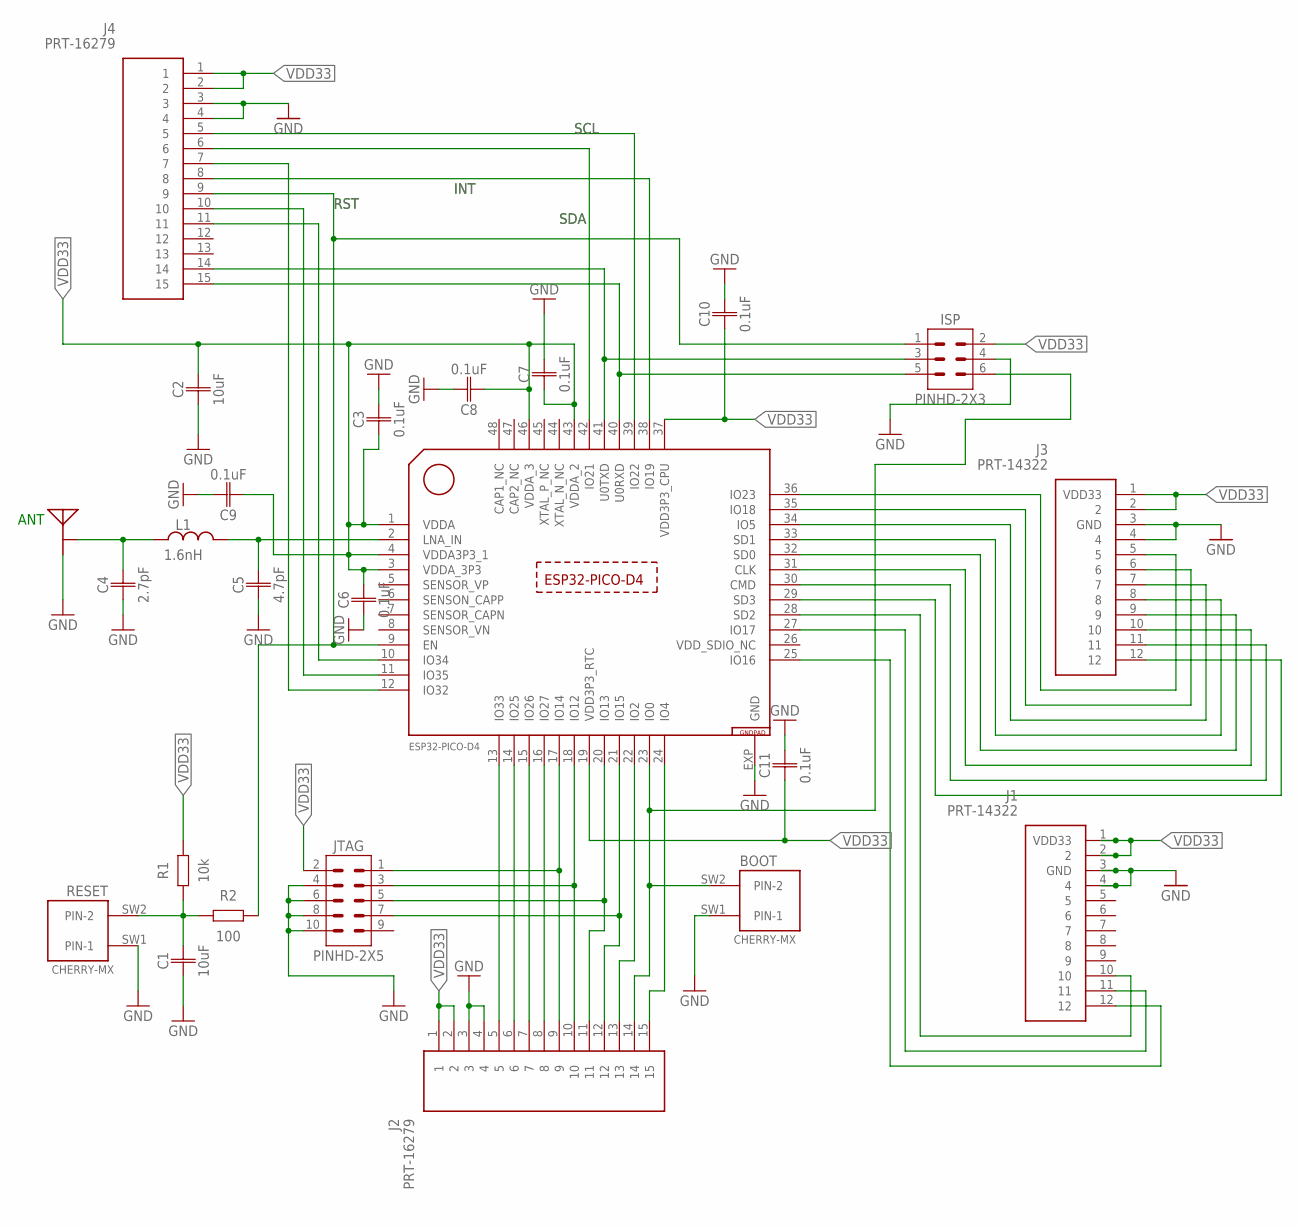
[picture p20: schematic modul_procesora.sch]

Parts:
ANT: ANT; MEANDER-ANT
BOOT: BOOT; CHERRY-MX
C1, C2: 10uF; CAPC1005X60
C3, C6, C7, C8, C9, C10, C11: 0.1uF; CAPC1005X60
C4: 2.7pF; CAPC1005X60
C5: 4.7pF; CAPC1005X60
ISP: PINHD-2X3; 2X03
J1, J3: PRT-14322; RHDR12W87P0X254_1X12_3103X250X
J2, J4: PRT-16279; PRT16279
JTAG: PINHD-2X5; 2X05
L1: 1.6nH; INDC1006X60N
R1: 10k; RESC1005X40
R2: 100; RESC1005X40
RESET: CHERRY-MX
U$1: ESP32-PICO-D4; QFN48

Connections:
GND: ANT.FEED, BOOT.SW1 (PIN-1), C1.1, C2.1, C3.2, C4.1, C5.1, C6.1, C7.2, C8.2, C9.2, C10.2, C11.2, ISP.4, J1.3 (GND), J1.4, J2.3, J2.4, J3.3 (GND), J3.4, J4.3, J4.4, JTAG.4, JTAG.6, JTAG.8, JTAG.10, RESET.SW1 (PIN-1), U$1.EXP (GND)
INT: J4.8, U$1.38 (IO19)
unnamed: BOOT.SW2 (PIN-2), ISP.6, J2.14, U$1.23 (IO0)
unnamed: C1.2, R1.1, R2.1, RESET.SW2 (PIN-2)
unnamed: J2.9, JTAG.1, U$1.17 (IO14)
unnamed: J2.10, JTAG.3, U$1.18 (IO12)
unnamed: J2.11, JTAG.5, U$1.20 (IO13)
unnamed: J2.12, JTAG.7, U$1.21 (IO15)
unnamed: ISP.5, J4.15, U$1.40 (U0RXD)
unnamed: ISP.3, J4.14, U$1.41 (U0TXD)
unnamed: ANT.GND, C4.2, L1.1
unnamed: C5.2, L1.2, U$1.2 (LNA_IN)
unnamed: J3.5, U$1.36 (IO23)
unnamed: J3.6, U$1.35 (IO18)
unnamed: J3.7, U$1.34 (IO5)
unnamed: J3.8, U$1.33 (SD1)
unnamed: J3.9, U$1.32 (SD0)
unnamed: J3.10, U$1.31 (CLK)
unnamed: J3.11, U$1.30 (CMD)
unnamed: J3.12, U$1.29 (SD3)
unnamed: J1.10, U$1.28 (SD2)
unnamed: J1.11, U$1.27 (IO17)
unnamed: J1.12, U$1.25 (IO16)
unnamed: J2.15, U$1.24 (IO4)
unnamed: J2.13, U$1.22 (IO2)
unnamed: J2.8, U$1.16 (IO27)
unnamed: J2.7, U$1.15 (IO26)
unnamed: J2.6, U$1.14 (IO25)
unnamed: J2.5, U$1.13 (IO33)
unnamed: J4.7, U$1.12 (IO32)
unnamed: J4.10, U$1.11 (IO35)
unnamed: J4.11, U$1.10 (IO34)
RST: ISP.1, J4.9, R2.2, U$1.9 (EN)
SCL: J4.5, U$1.39 (IO22)
SDA: J4.6, U$1.42 (IO21)
VDD33: C2.2, C3.1, C6.2, C7.1, C8.1, C9.1, C10.1, C11.1, ISP.2, J1.1 (VDD33), J1.2, J2.1, J2.2, J3.1 (VDD33), J3.2, J4.1, J4.2, JTAG.2, R1.2, U$1.1 (VDDA), U$1.3 (VDDA_3P3), U$1.4 (VDDA3P3_1), U$1.19 (VDD3P3_RTC), U$1.37 (VDD3P3_CPU), U$1.43 (VDDA_2), U$1.46 (VDDA_3)
VDD_SDIO_NC: U$1.26 (VDD_SDIO_NC)

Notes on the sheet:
ANT
SDA
INT
RST
SCL

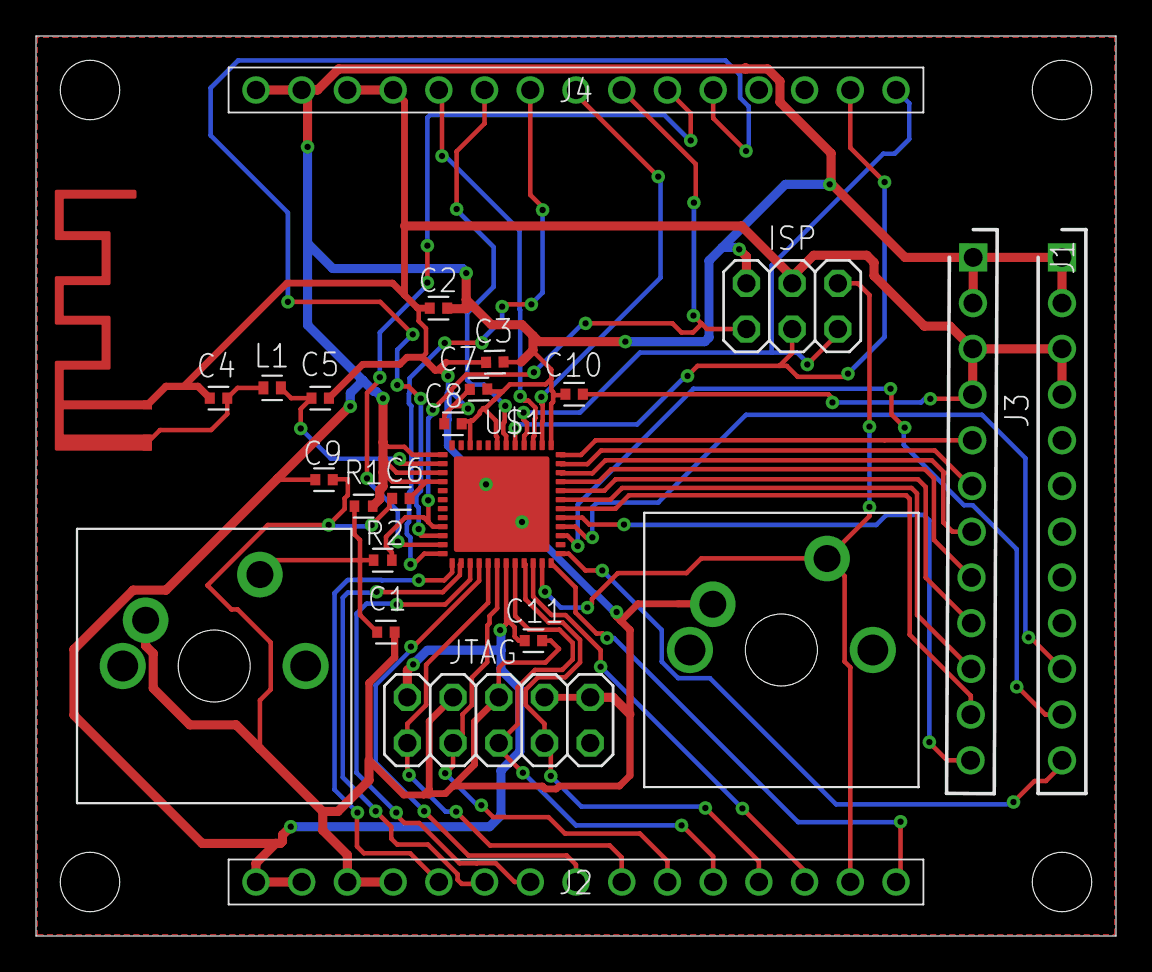
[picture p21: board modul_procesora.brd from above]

Board: 2 copper layers, 60.0 x 50.0 mm, 28 parts (0 on the bottom side), 36 nets.

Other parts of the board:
STANDOFF1, STANDOFF2, STANDOFF3, STANDOFF4: STAND-OFF

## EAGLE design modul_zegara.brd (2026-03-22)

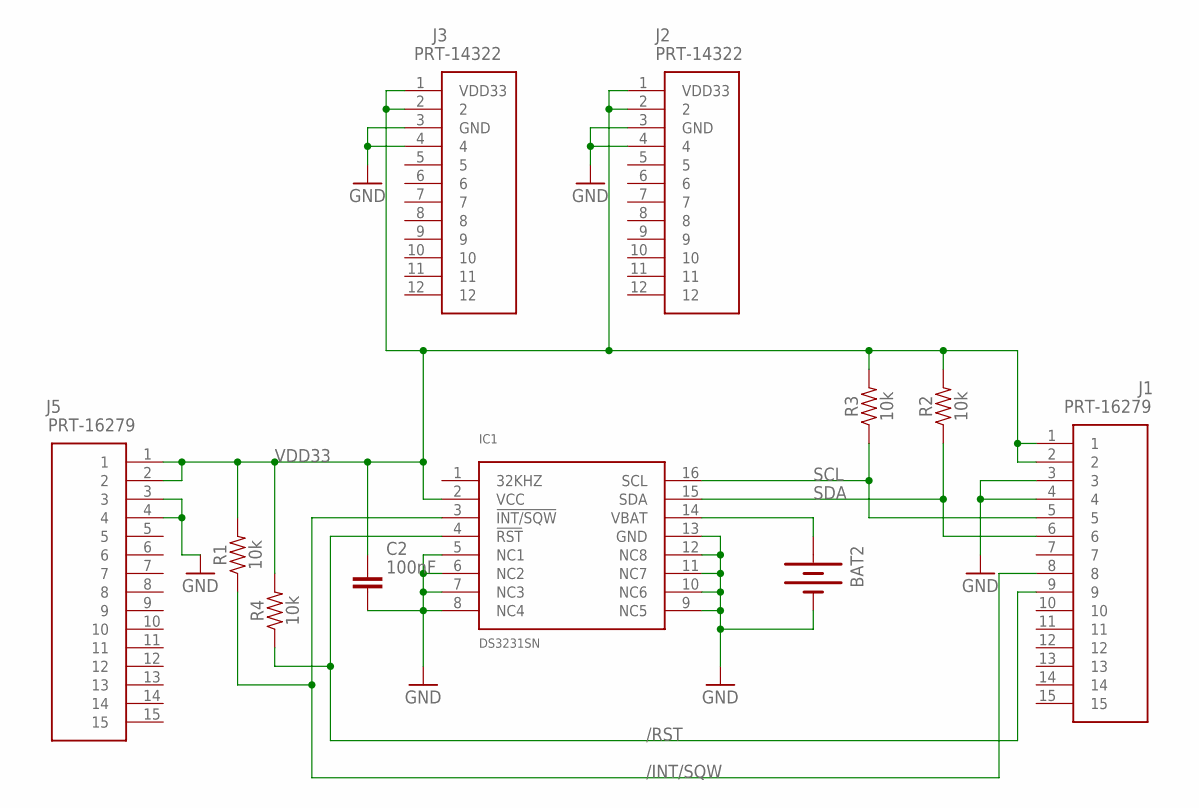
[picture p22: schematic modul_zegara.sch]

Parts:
BAT2: BATTERY20PTH; BATTCOM_20MM_PTH
C2: 100nF; CAPC3216X135
IC1: DS3231SN; SO16W
J1, J5: PRT-16279; PRT16279
J2, J3: PRT-14322; RHDR12W87P0X254_1X12_3103X250X
R1, R2, R3, R4: 10k; AXIAL-0.3

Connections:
/INT/SQW: IC1.3 (!INT/SQW), J1.8, R1.P$1 (1)
/RST: IC1.4 (!RST), J1.9, R4.P$1 (1)
GND: BAT2.2 (-), C2.2, IC1.5 (NC1), IC1.6 (NC2), IC1.7 (NC3), IC1.8 (NC4), IC1.9 (NC5), IC1.10 (NC6), IC1.11 (NC7), IC1.12 (NC8), IC1.13 (GND), J1.3, J1.4, J2.3 (GND), J2.4, J3.3 (GND), J3.4, J5.3, J5.4
unnamed: BAT2.1 (+), IC1.14 (VBAT)
SCL: IC1.16 (SCL), J1.5, R3.P$1 (1)
SDA: IC1.15 (SDA), J1.6, R2.P$1 (1)
VDD33: C2.1, IC1.2 (VCC), J1.1, J1.2, J2.1 (VDD33), J2.2, J3.1 (VDD33), J3.2, J5.1, J5.2, R1.P$2 (2), R2.P$2 (2), R3.P$2 (2), R4.P$2 (2)

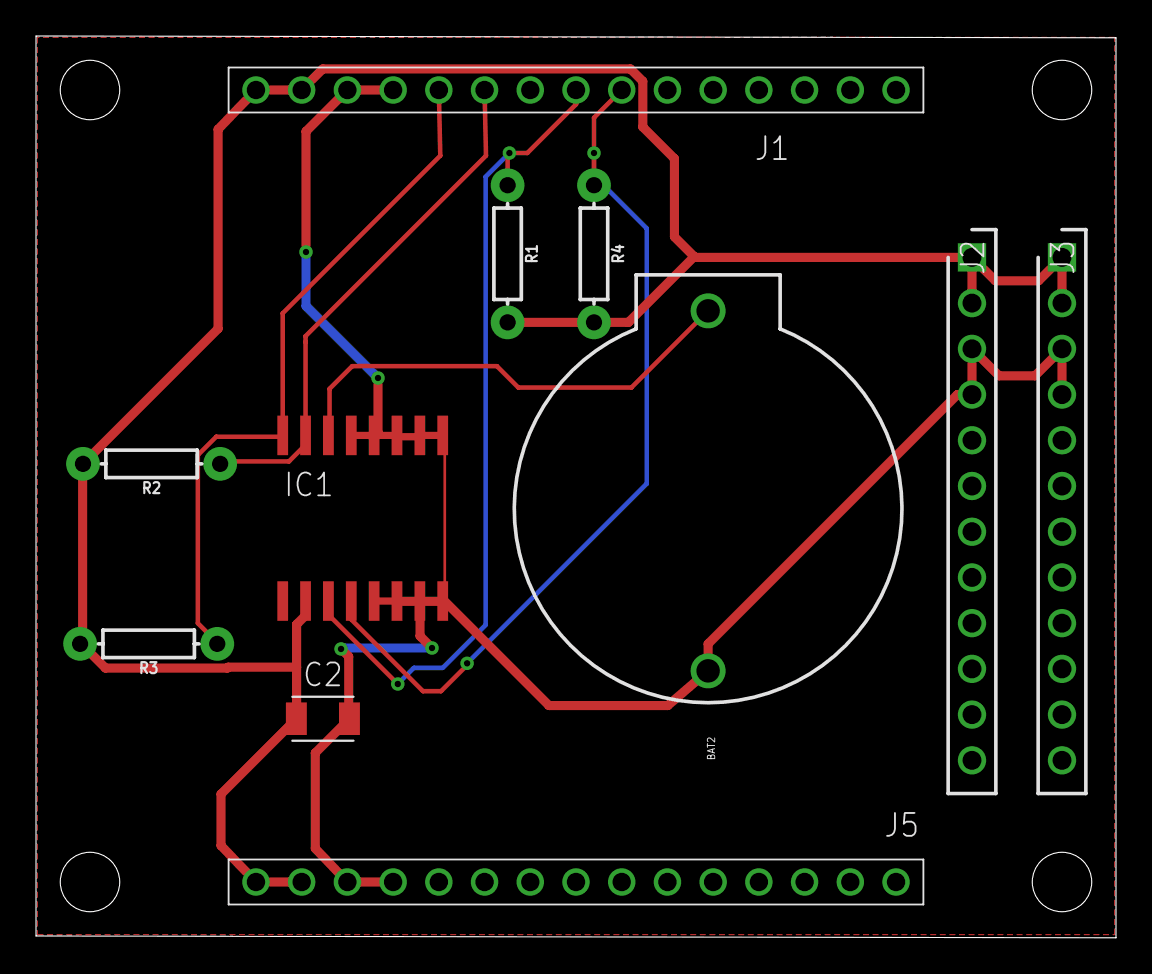
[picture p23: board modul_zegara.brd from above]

Board: 2 copper layers, 60.0 x 50.1 mm, 15 parts (0 on the bottom side), 7 nets.

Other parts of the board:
STANDOFF1, STANDOFF2, STANDOFF3, STANDOFF4: STAND-OFF

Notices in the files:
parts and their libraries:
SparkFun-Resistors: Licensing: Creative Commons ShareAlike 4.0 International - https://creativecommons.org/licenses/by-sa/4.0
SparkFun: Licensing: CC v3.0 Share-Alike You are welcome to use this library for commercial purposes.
